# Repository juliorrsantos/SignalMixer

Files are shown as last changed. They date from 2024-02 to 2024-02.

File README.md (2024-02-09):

# Misturador de sinais

## Circuito desenvolvido como complemento para estudos de FFT
O diagrama esquemático do circuito pode ser conferido **[aqui](./KiCad/SignalMixer/SignalMixer.pdf).**

Características:
- Duas entradas de sinais analógicos, com opção de alta impedância de entrada ou 50 ohms.
- configuração de ganho por canal de 1x, 10x, 100X e valores intermediarios pela combinação dos resistores.
- Alimentação por fonte simples de 24Vcc.
- A saída será o resultado da soma dos dois sinais de entrada, multiplicado por seus respectivos ganhos.

obs.: A fonte utilizada para alimentação do circuito não deverá ser a mesma que alimenta o gerador de sinais da entrada, ou o circuito conectado à saída.

## Imagens da placa

### Vista frontal
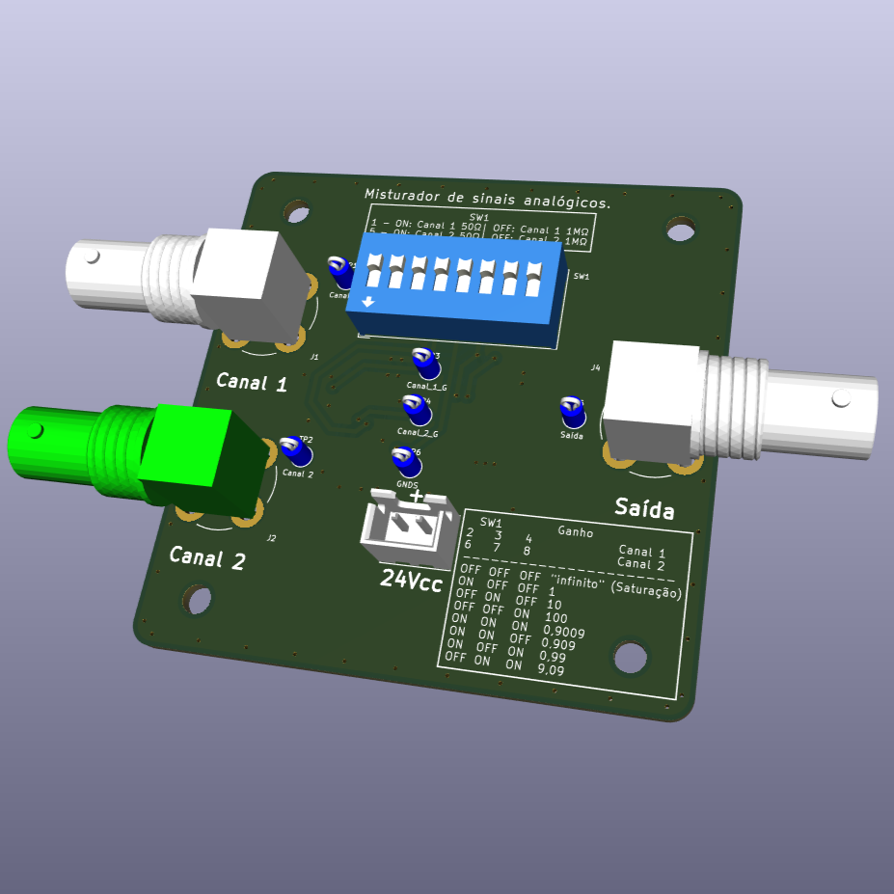
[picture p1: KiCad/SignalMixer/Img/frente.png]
Vista frontal da PCI Vista frontal da PCB


### Vista traseira
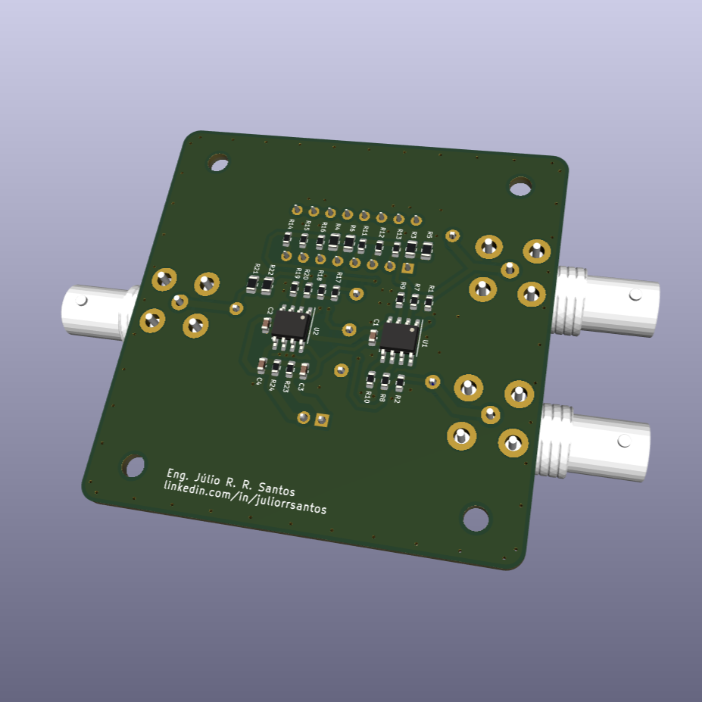
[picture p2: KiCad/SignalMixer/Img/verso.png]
Vista traseira da PCI

## Simulação

Simulação do circuito no LTspice com a injeção de duas senoides, em 60 e 1200Hz respectivamente. Ambas com tensão de pico de 1V.

É possível notar a soma dos dois sinais no terceiro gráfico, comprovando o funcionamento do circuito.

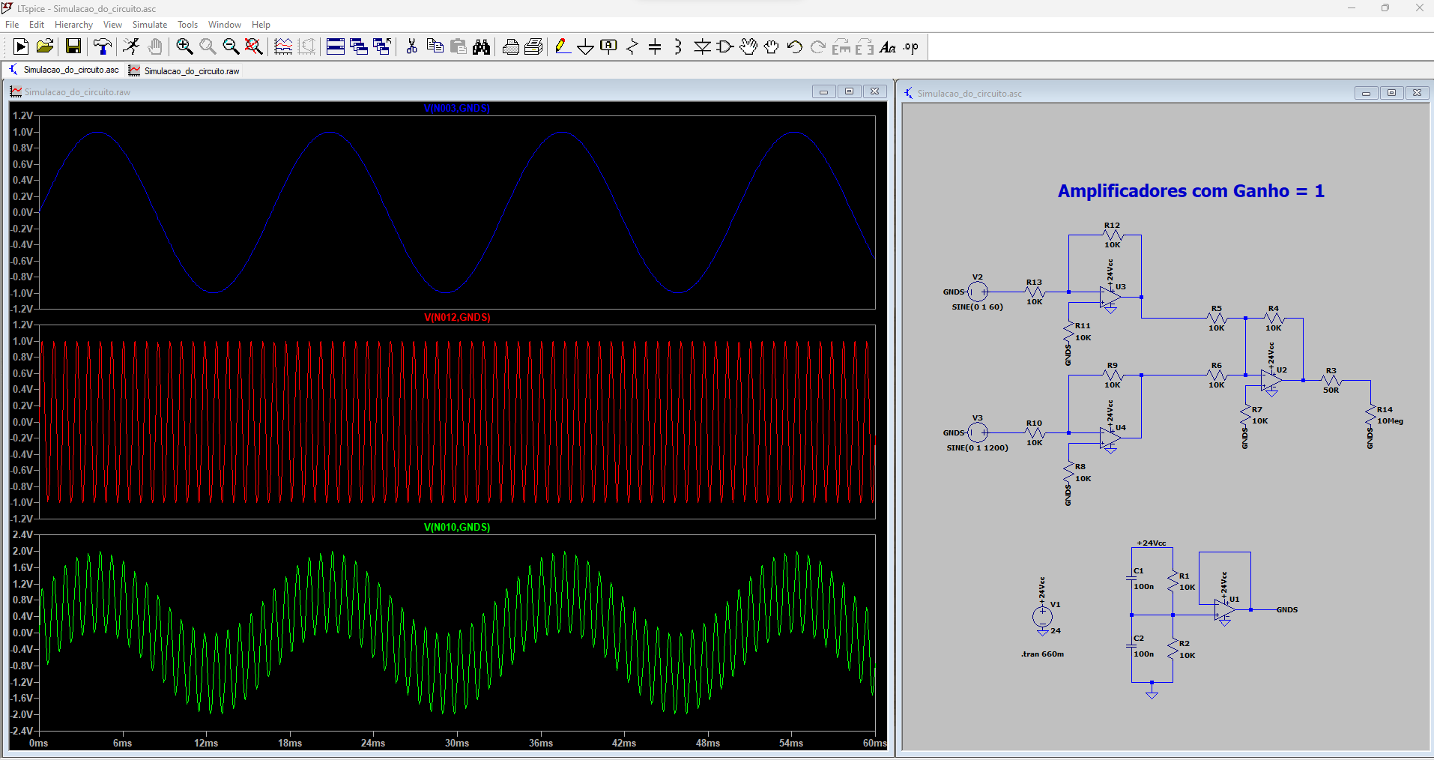
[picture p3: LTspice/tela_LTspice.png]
Simulação em LTspice


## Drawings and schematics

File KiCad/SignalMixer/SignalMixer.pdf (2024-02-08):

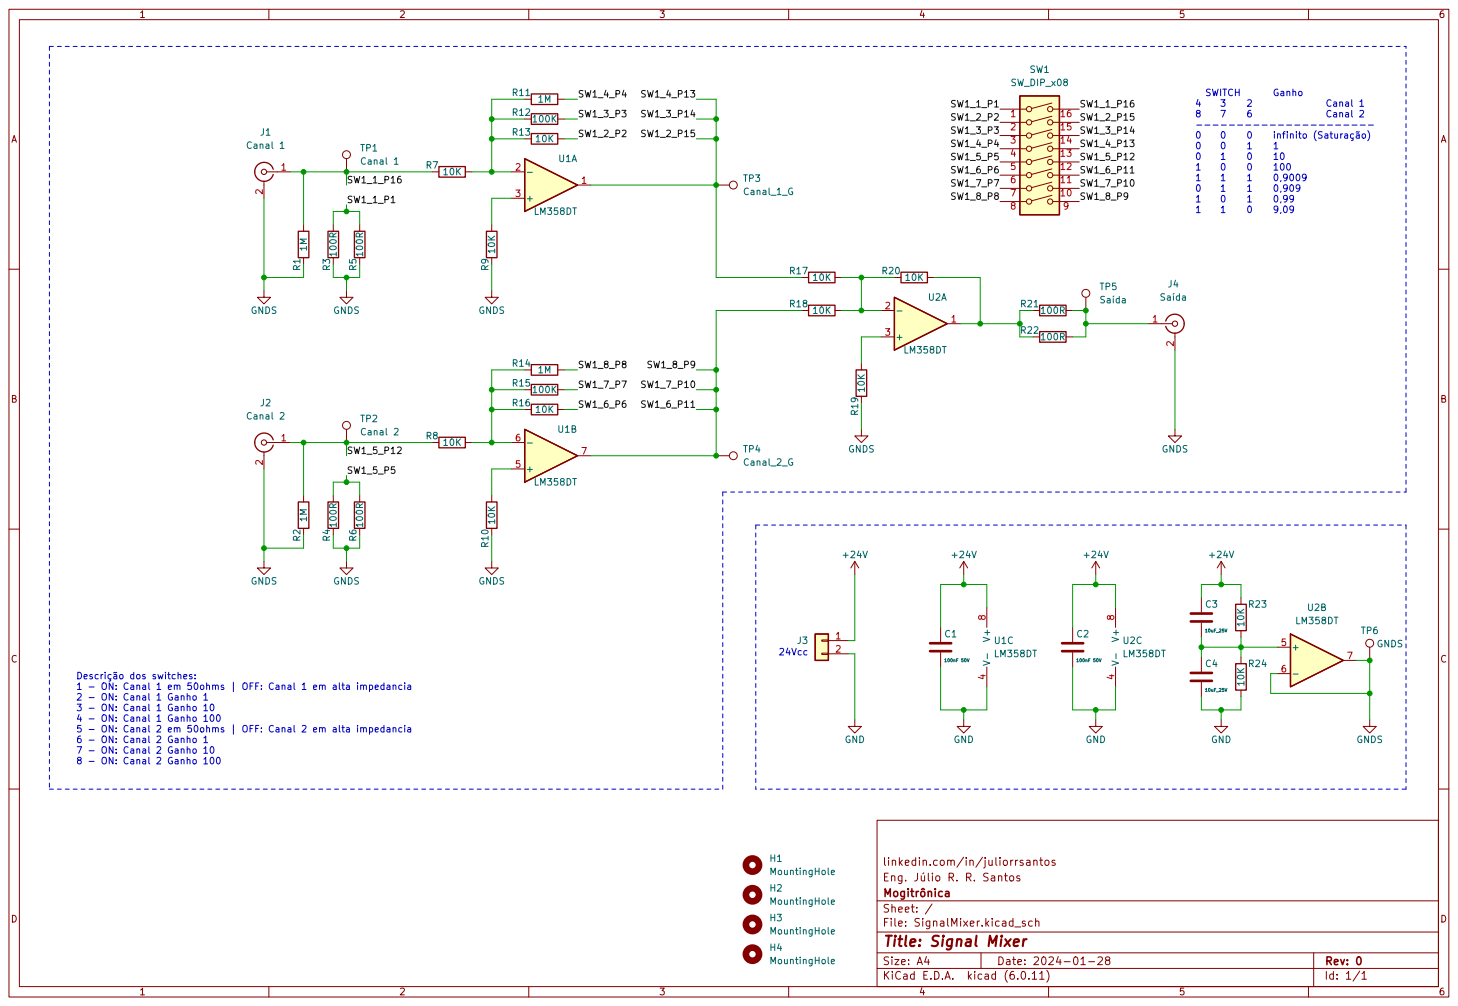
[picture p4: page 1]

Eng. þÿJúlio R. R. Santos
Id: 1/1 Title: Signal Mixer File: SignalMixer.kicad_sch Sheet: / þÿMogitrônica

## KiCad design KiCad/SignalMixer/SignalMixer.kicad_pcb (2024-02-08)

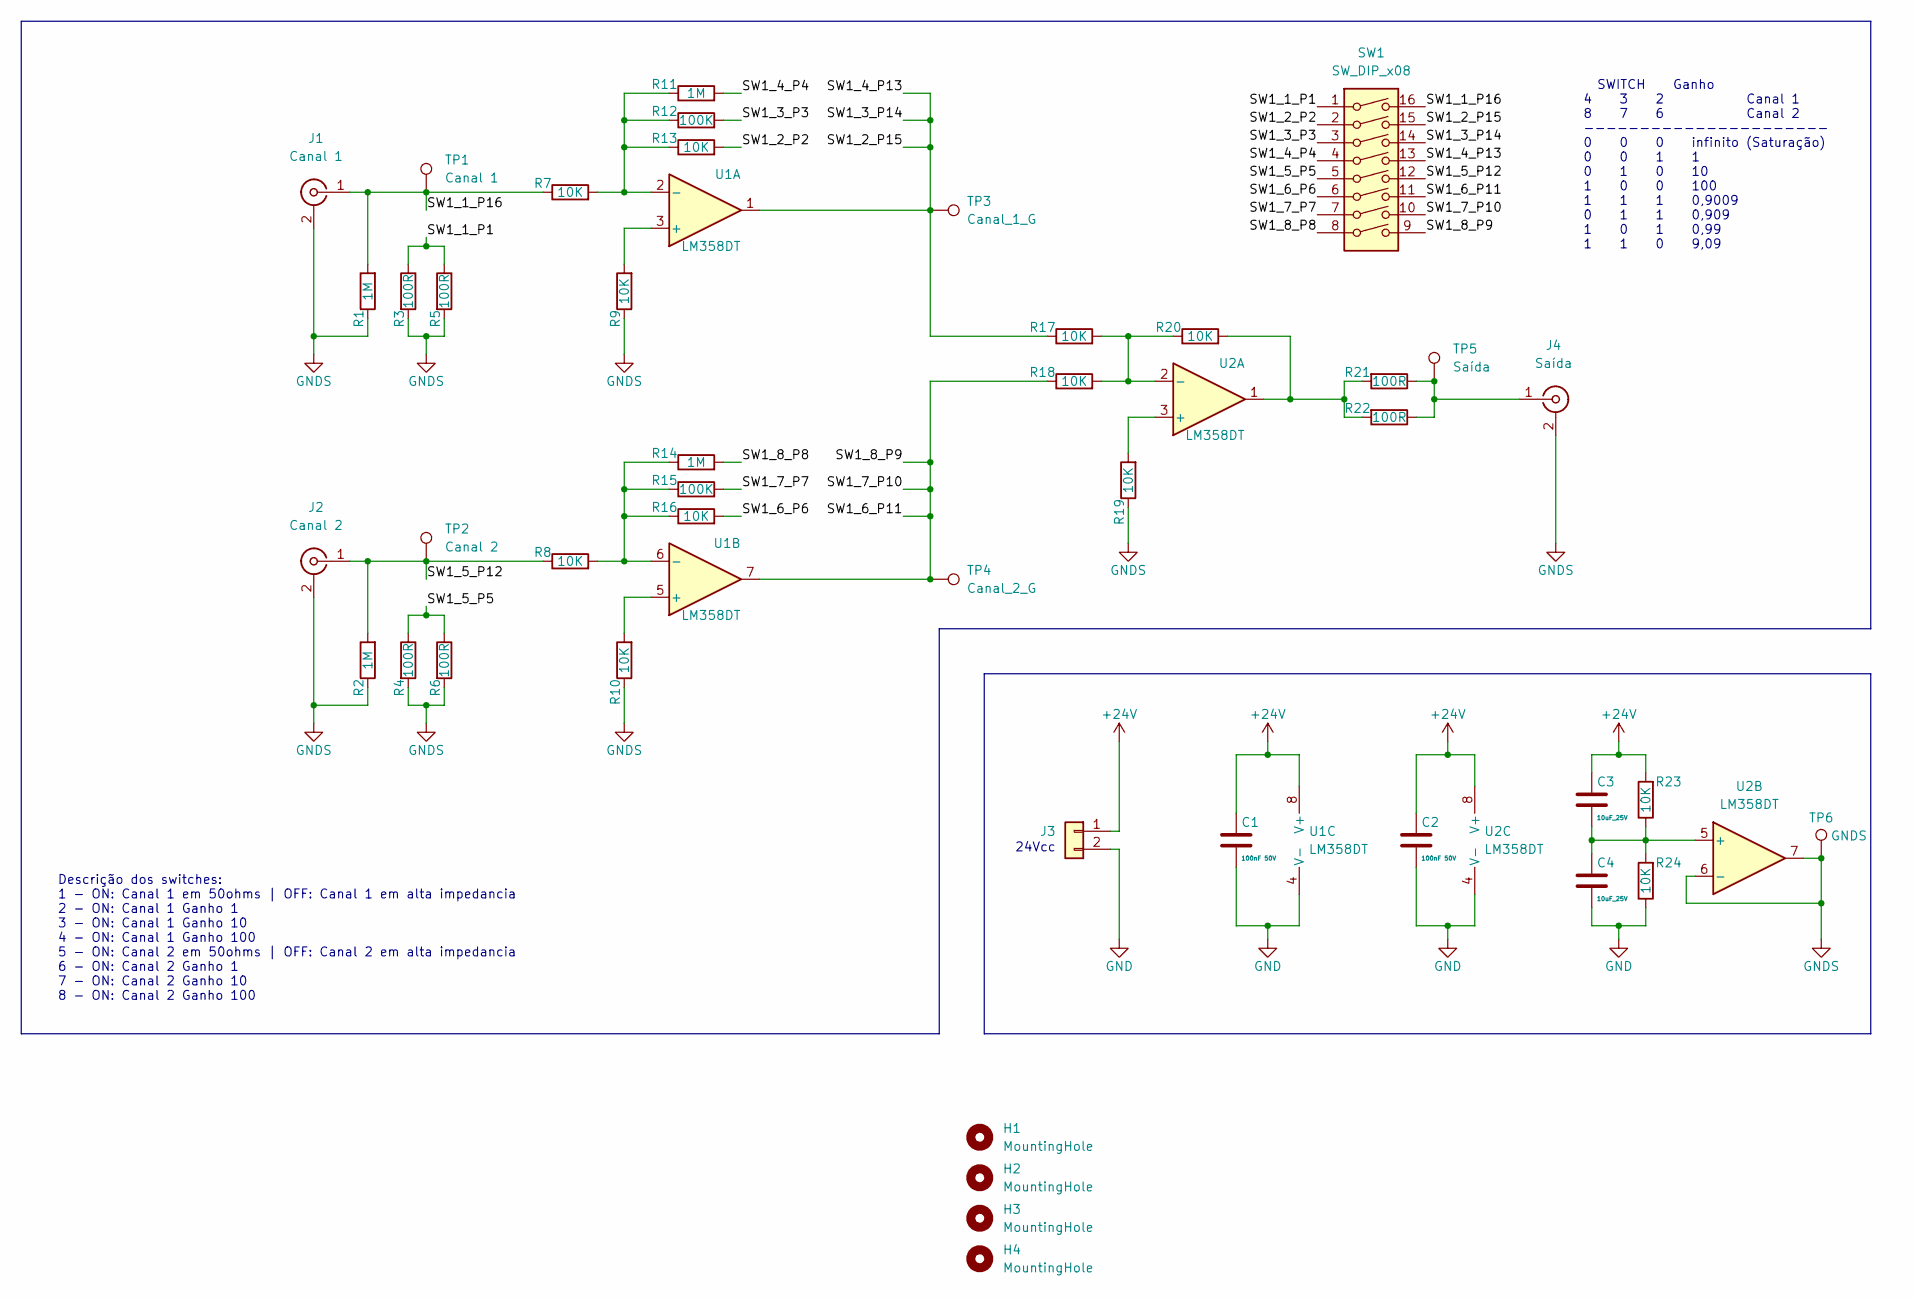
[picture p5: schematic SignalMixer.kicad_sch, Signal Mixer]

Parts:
C1, C2: 100nF 50V; C_0603_1608Metric; LCSC C1591
C3, C4: 10uF_25V; C_0603_1608Metric; LCSC C96446
H1, H2, H3, H4: MountingHole; MountingHole_3.2mm_M3
J1: Canal 1; BNC_DOSIN-801-0083
J2: Canal 2; BNC_DOSIN-801-0083
J3: Conn_01x02; JST_XH_B02B-XH-A_02x2.50mm_Straight
J4: Saída; BNC_DOSIN-801-0083
R1, R2, R11, R14: 1M; R_0603_1608Metric; LCSC C22935
R3, R4, R5, R6, R21, R22: 100R; R_0805_2012Metric; LCSC C17408
R7, R8, R9, R10, R13, R16, R17, R18, R19, R20, R23, R24: 10K; R_0603_1608Metric; LCSC C25804
R12, R15: 100K; R_0603_1608Metric; LCSC C25803
SW1: SW_DIP_x08; SW_DIP_SPSTx08_Slide_9.78x22.5mm_W7.62mm_P2.54mm
TP1: Canal 1; TestPoint_RH-5000; LCSC C5277086
TP2: Canal 2; TestPoint_RH-5000; LCSC C5277086
TP3: Canal_1_G; TestPoint_RH-5000; LCSC C5277086
TP4: Canal_2_G; TestPoint_RH-5000; LCSC C5277086
TP5: Saída; TestPoint_RH-5000; LCSC C5277086
TP6: GNDS; TestPoint_RH-5000; LCSC C5277086
U1, U2: LM358DT; SOIC-8_3.9x4.9mm_P1.27mm; LCSC C9418

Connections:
+24V: C1.1, C2.1, C3.1, J3.1, R23.2, U1.8 (V+), U2.8 (V+)
/SW1_1_P1: R3.1, R5.1, SW1.1
/SW1_1_P16: J1.1 (In), R1.2, R7.1, SW1.16, TP1.1
/SW1_2_P2: R13.2, SW1.2
/SW1_2_P15: R17.1, SW1.13, SW1.14, SW1.15, TP3.1, U1.1
/SW1_3_P3: R12.2, SW1.3
/SW1_4_P4: R11.2, SW1.4
/SW1_5_P5: R4.1, R6.1, SW1.5
/SW1_5_P12: J2.1 (In), R2.2, R8.1, SW1.12, TP2.1
/SW1_6_P6: R16.2, SW1.6
/SW1_6_P11: R18.1, SW1.9, SW1.10, SW1.11, TP4.1, U1.7
/SW1_7_P7: R15.2, SW1.7
/SW1_8_P8: R14.2, SW1.8
GND: C1.2, C2.2, C4.2, J3.2, R24.1, U1.4 (V-), U2.4 (V-)
GNDS: J1.2 (Ext), J2.2 (Ext), J4.2 (Ext), R1.1, R2.1, R3.2, R4.2, R5.2, R6.2, R9.1, R10.1, R19.1, TP6.1, U2.6 (-), U2.7
unnamed: C3.2, C4.1, R23.1, R24.2, U2.5 (+)
unnamed: J4.1 (In), R21.1, R22.1, TP5.1
unnamed: R9.2, U1.3 (+)
unnamed: R10.2, U1.5 (+)
unnamed: R7.2, R11.1, R12.1, R13.1, U1.2 (-)
unnamed: R8.2, R14.1, R15.1, R16.1, U1.6 (-)
unnamed: R17.2, R18.2, R20.1, U2.2 (-)
unnamed: R19.2, U2.3 (+)
unnamed: R20.2, R21.2, R22.2, U2.1

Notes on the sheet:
24Vcc
Descrição dos switches: 1 - ON: Canal 1 em 50ohms | OFF: Canal 1 em alta impedancia 2 - ON: Canal 1 Ganho 1 3 - ON: Canal 1 Ganho 10 4 - ON: Canal 1 Ganho 100 5 - ON: Canal 2 em 50ohms | OFF: Canal 2 em alta impedancia 6 - ON: Canal 2 Ganho 1 7 - ON: Canal 2 Ganho 10 8 - ON: Canal 2 Ganho 100
SWITCH Ganho 4 3 2 Canal 1 8 7 6 Canal 2 ---------------------- 0 0 0 infinito (Saturação) 0 0 1 1 0 1 0 10 1 0 0 100 1 1 1 0,9009 0 1 1 0,909 1 0 1 0,99 1 1 0 9,09

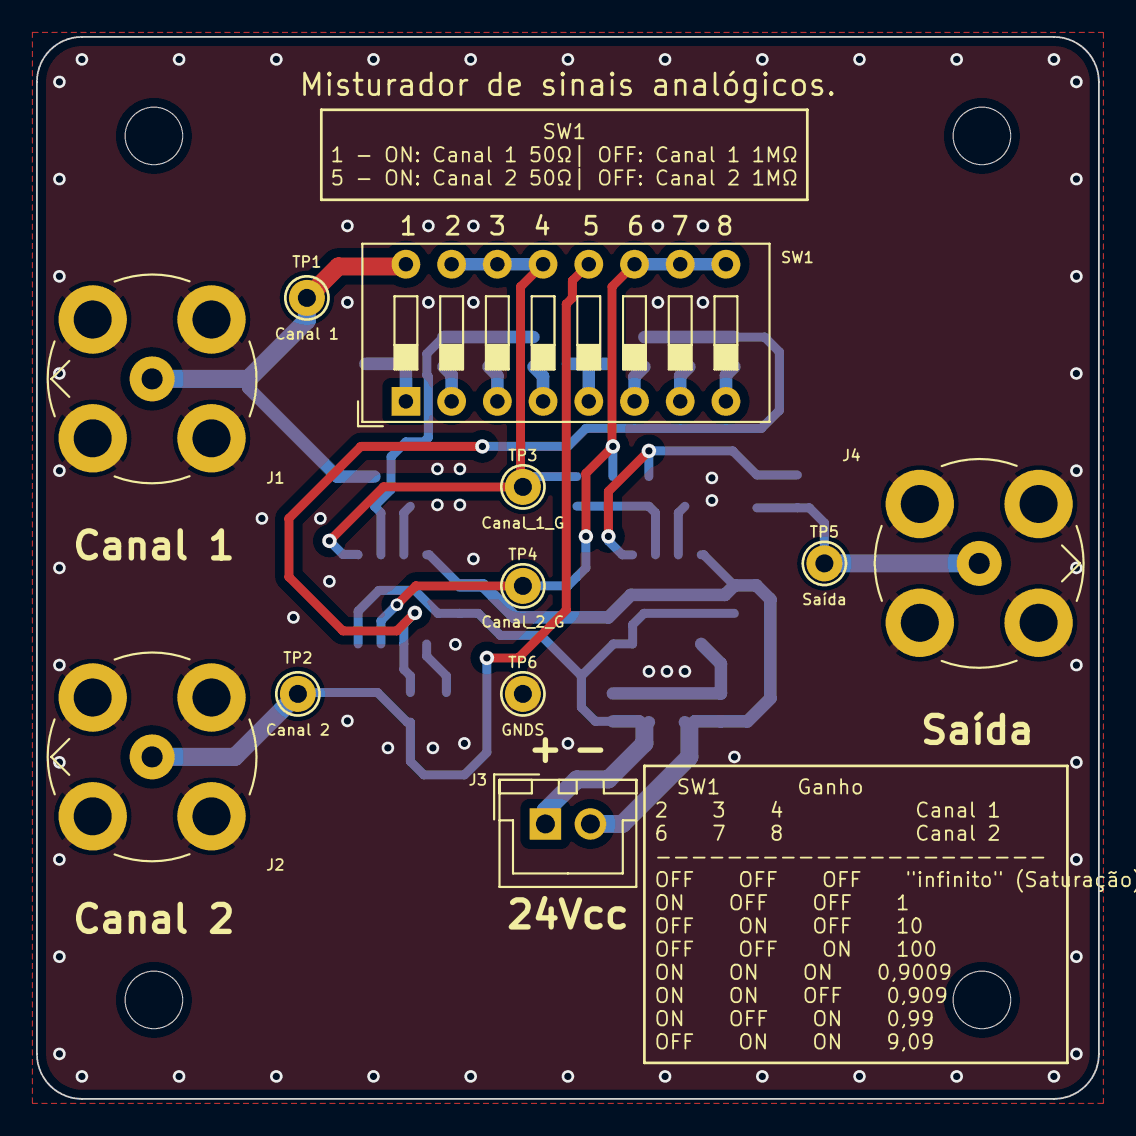
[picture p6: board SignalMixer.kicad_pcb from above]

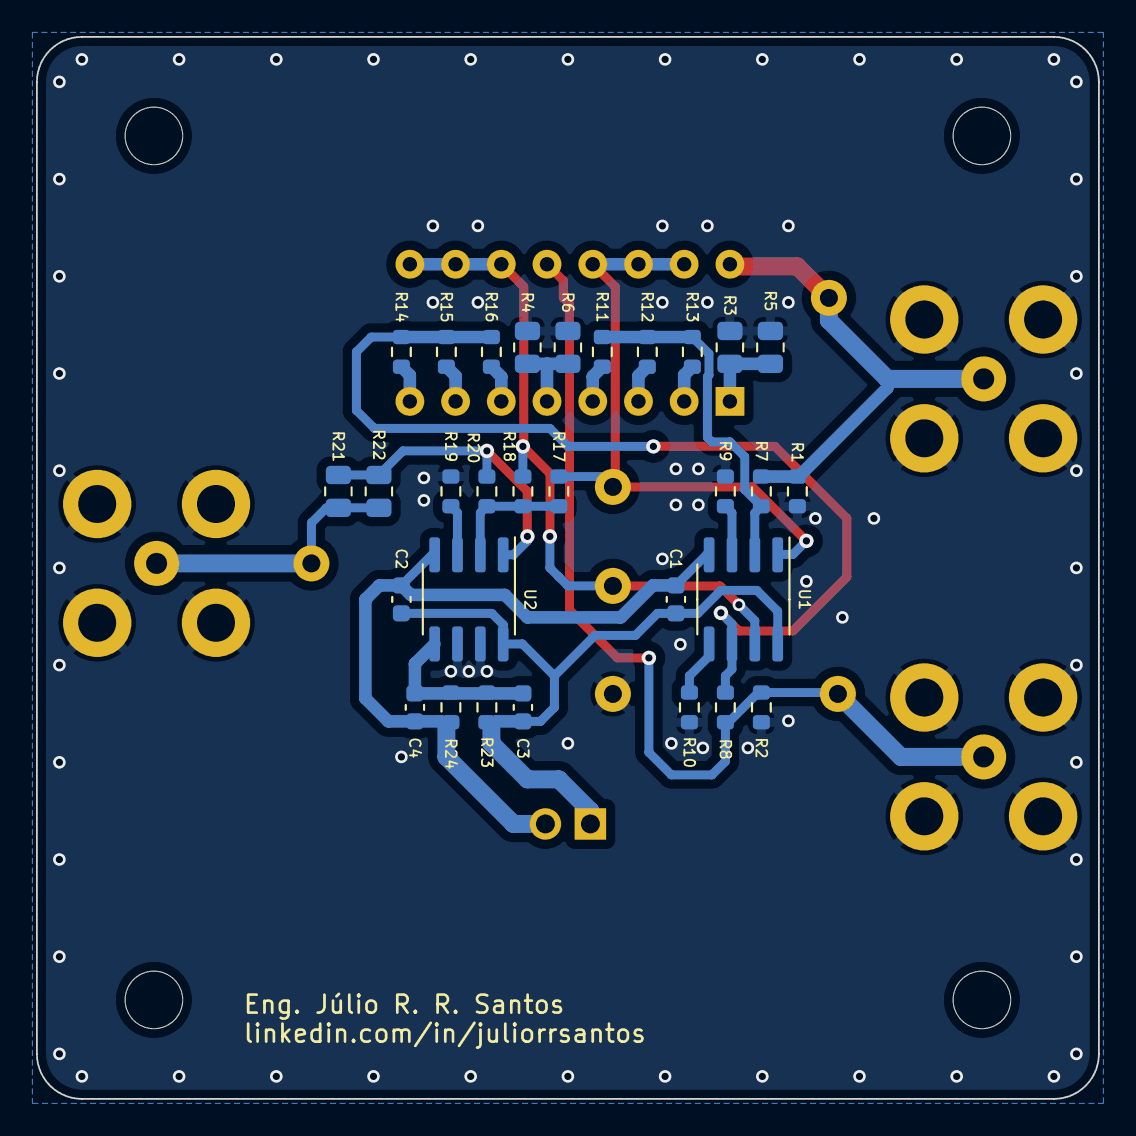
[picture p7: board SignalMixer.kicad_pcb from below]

Board: 2 copper layers, 59.0 x 59.0 mm, 45 parts (30 on the bottom side), 24 nets.

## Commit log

2024-01-28 Definição inicial das características do circuito
2024-01-28 Atualização nas características de projeto.
2024-01-28 Criacao do diagrama esquematico.
    [SignalMixer.kicad_pcb, SignalMixer.kicad_sch]
2024-01-29 Finalização do diagrama esquematico e geração do diagrama em PDF.
    [SignalMixer.kicad_sch]
2024-01-29 Adicionado resistor de 1M nas entradas para evitar flutuacao quando o resistor de 50 ohms for desconectado.
    [SignalMixer.kicad_sch]
2024-02-01 Definicao dos footprints, atualizacao do esquematico e inicio do roteamento da pcb.
    [SignalMixer.kicad_pcb, SignalMixer.kicad_sch]
2024-02-08 Finalizacao do layout da PCB.
    [SignalMixer.kicad_pcb, SignalMixer.kicad_sch]
2024-02-08 Inclusao de imagens no Readme.
